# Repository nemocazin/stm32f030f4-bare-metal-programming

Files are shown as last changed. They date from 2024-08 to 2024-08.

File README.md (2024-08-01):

# STM32F030F4 Bare metal programming





## Table of content

 * [General project information](#general-project-information)
 * [Electronic board design](#electronic-board-design)
 * [Embedded programming and test design](#embedded-programming-and-test-design)
 * [Contact](#contact)

## General project information

This product was developed as part of a fourth-year project in the Embedded Systems program at Polytech Lille with an another student. It consisted in designing an electronic board to measure temperature and store the values in an EPROM-type memory. We had to create the board and the programming ourselves, __in a context of mass production__. As a result, we had to work as if we were in a company, meaning we had to carry out all the design stages of a product. 

__This project is focused on the test and maintenance part of the project__. Whether we were testing the physical board or the programming part, we had to do our best to ensure that the board worked in spite of the environment and all its constraints.

The project is therefore divided in __two parts__ : the physical part with the electronic board, and the programming part with the embedded program and the tests carried out on it.

## Electronic board design

This part consists of designing the electronic board. The purpose of this board is to __measure temperature and store measured values in an EPROM-type memory__. We were then asked to design certain components, such as the temperature sensor. 

We then designed the board on Kicad-6 and drew up the schematic and routing. In the end, the board was designed on Polytech Lille's site, from manufacturing to soldering.

We also carried out tests on the board to see how it performed in certain types of environment. 

The board design files can be found in the _"PCB"_ folder of the current directory.

## Embedded programming and test design

The programming of the card was mainly __carried out in the C programming language and using bare metal programming__.

We also used the _"check.h"_ library to carry out unit tests and ensure the proper functioning of our code.

Nucleo boards were available to transfer our file to our microcontroller

## Contact

Created by [@nemocazin] & Antoine Cegarra

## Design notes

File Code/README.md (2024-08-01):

# STM32F030F4 Bare metal programming
# __Embedded Programming Part__

## Table of content

 * [General project information](#general-project-information)
 * [Makefile](#makefile)
 * [tests directory](#tests-directory)
 * [src directory](#src-directory)
 * [lib directory](#lib-directory)
 * [build directory](#build-directory)
 * [Picture](#picture)
 * [Documentation used](#documentation-used)
 * [Contact](#contact)

## General design information

For the embedded programming part of this project, we had to code the ARM Cortex microcontroller using bare metal programming. This program is therefore in the form of an .elf file to be injected into the microcontroller via the ARM JTAG connector. In addition, we had to run unit tests all around the code to check that it worked properly.

## Makefile

The makefile is made up of several targets, each of which performs a specific task.
 - The __main target__ compiles files in the _"src"_ directory using the _"arm-none-eabi-gcc"_ compiler. This needs its linker, which can be found in the _"lib"_ directory. This compiler generates an .elf file which can be injected into the microcontroller via the ARM JTAG connector. As we're creating embedded code, we optimize the size of the .elf file with the __"-O1"__ option. This option is only set to 1, because from 2 onwards, the compiler transforms optimizations made in the microcontroller startup file into functions not present in the libraries on the school's computers, as these libraries are not downloadable at school. These functions are, for example, memcpy and memset, which replace the optimization already carried out for copying SRAM into flash. Additionally, while testing the sensor voltage to temperature conversion function, we noticed that the "arm-none-eabi-gcc" compiler is not capable of using the "float" data type. ". However in our case, it is necessary to use it for the conversion. We then did research to activate floating points but we had to modify the compiler linker and the "mfloat-abi" option did not work even with the hard value.
- the __test target__ is used to create a test executable. These tests are only performed on the _"functions"_ file, as it is the only file with testable functions. We also use the gcc compiler instead of arm-none-eabi-gcc to create the executable file without errors.
- the __load target__ connects to the Nucleo board, enabling the embedded program to be transferred to the microcontroller.
- the __clean target__ deletes temporary files from the _"build"_ directory.
- the __coverage target__ is used to create files displaying the program's coverage. 

## tests directory

This directory __contains the C file for all tests performed__. It performs unit tests on the functions in the _"functions.c"_ file. Tests are mainly performed on register values.

## src directory

This directory contains all the files needed to create the .elf file that can be injected into the microcontroller via the ARM JTAG connector. It is made up of several files: 
 - The __"functions.h"__ file defines all register addresses and function prototypes in its .c file. Register addresses can be found in the datasheet starting on page 38 (Reference manual --> Documentation / Reference Manuals on the 2nd link).
 - the __"functions.c"__ file is used to define all functions and modify all registers to use the components. In general, registers are defined on 16 bits corresponding to 16 pins, and a bit 1 must be set at the corresponding register location. However, the _GPIOA_MODER register_ is defined on 32 bits, so you need to work on 2 bits for each pin. 
 - the __"stm32_startup"__ file is used to configure the microcontroller, since we're programming in bare metal. We then need to define each handler and each corresponding section for it to work. We must also add that the SRAM is 4kb and the Flash is 16kb. This file has been adapted from the tutorial available in the documentation (1st link).
 - the __"main"__ file is the file that calls the functions. The _RCC_AHBENR register_ is configured for clock A, which enables PAx pins to be used.
In the __"functions.h"__ and __"functions.h"__ files, defines vary depending on whether the file is used on an X86 machine or not. This is to enable testing of register values and avoid volatile conflicts. 

## lib directory

This directory contains libraries used when compiling and transferring the .elf file :
 - the __"stm32f030f4.ld"__ file corresponds to the linker used by the compiler thanks to the -T option and it explains how the different sections of the startup file must be brought together to create the .elf file. It also contains zone definitions, addresses and memory sizes.
 - the __"stm32nucleo.cfg"__ file is the file allowing the connection with the Nucleo debug board.

## build directory

This directory corresponds to the directory where the compiled files are stored. These files are erased during the "make clean" command.

## Picture

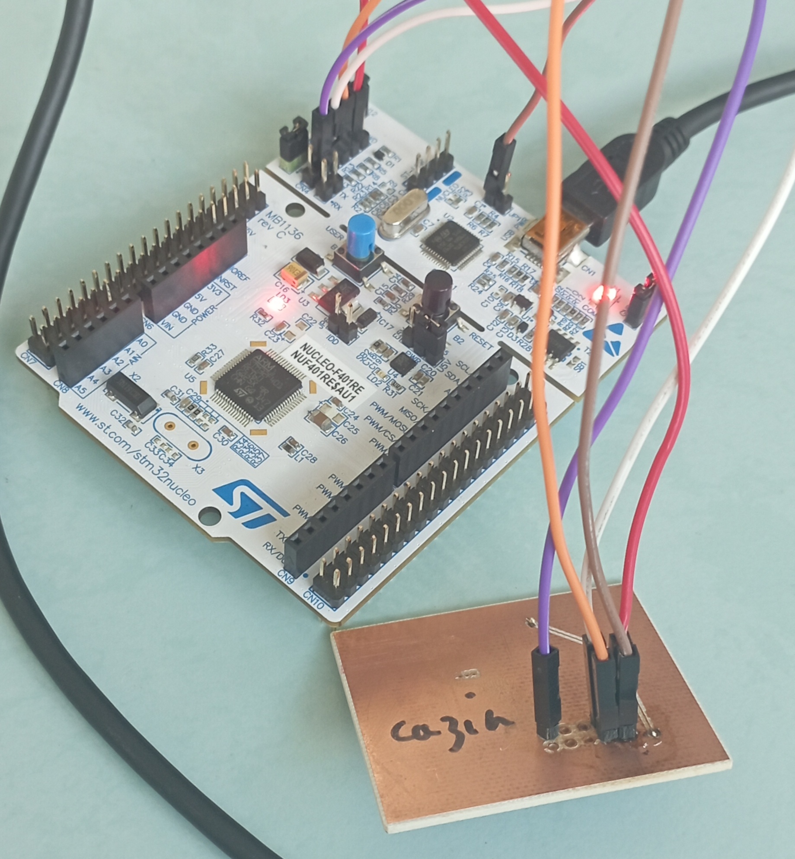
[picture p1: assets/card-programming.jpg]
Card programmation


## Documentation used

* _[Bare Metal - From zero to blink](https://linuxembedded.fr/2021/02/bare-metal-from-zero-to-blink)_
* _[Arm Cortex-M0 Datasheet](https://www.st.com/en/microcontrollers-microprocessors/stm32f030f4.html#documentation)_
* _[Bare metal STM32 Examples](https://github.com/joved-git/Bare_Metal_STM32/blob/master/stm32f103x/stm32_startup_f103x.c)_
* _[Functions of the lib "check.h"](https://libcheck.github.io/check/doc/check_html/check_4.html)_
* _[Options of the arm-none-eabi-gcc compiler](https://gcc.gnu.org/onlinedocs/gcc/ARM-Options.html)_
* _[Forum on floating points for arm-none-eabi-gcc compiler](https://stackoverflow.com/questions/54534700/enabling-floating-point-emulation-in-gcc-arm-none-eabi)_

## Contact

Created by [@nemo.cazin.etu] & Antoine Cegarra

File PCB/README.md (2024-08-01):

# STM32F030F4 Bare metal programming
# __PCB Conception Part__

## Table of content

 * [General project information](#general-project-information)
 * [Schematic design](#cchematic-design)
    * [STM32F030F4 ARM Cortex microcontroller configuration](#stm32f030f4-arm-cortex-microprocessor-configuration)
    * [M24C01 EPROM memory configuration](#m24c01-eprom-memory-configuration)
    * [MCP9700 temperature sensor configuration](#mcp9700-temperature-sensor-configuration)
    * [ARM JTAG connector configuration](#arm-jtag-connector-configuration)
    * [Other components](#other-components)
    * [Decoupling capacitors](#decoupling-capacitors)
    * [TestPoints documentation](#testpoints-documentation)
 * [PCB design](#pcb-design)
 * [Gerber files](#gerber-files)
 * [Soldering](#soldering)
 * [Documentation used](#documentation-used)
 * [Contact](#contact)

## General design information

This project enabled us to design an electronic board for mass production. This put us in a real design situation, so we had to be rigorous in our work and explanations.
For the design of this electronic board, several components were imposed on us. Firstly, the microcontroller is an __STM32F030F4 Arm Cortex__ with a 32-bit RISC-V core. Next, we had to use a __1kbit M24C01 EPROM memory__ on the I2C serial bus. Last but not least, a __Low-Power Linear Active MCP9700 temperature sensor__ was required.
With this information on the components we needed, we began the schematic of our board.

## Schematic design

### STM32F030F4 ARM Cortex microcontroller configuration

As we're using an ARM Cortex microcontroller, we had to do a lot of research to create the schematic around this component. First of all, the __NRST pin__ corresponds to the reset and a 0.1uF capacitor is connected. This information comes from the microcontroller documentation, so we did the same. 
The __BOOTO pin__ is used to control the microcontroller's start-up mode. _When the pin is in the low state (0)_, the microcontroller starts normally from its internal flash memory, where the user program is stored. On the contrary, _when the pin is high (1)_, the microcontroller starts up in special boot mode. This means it will attempt to boot from a different boot source, such as a connected programming device (like an ST-Link or bootloader), or from external memory (like separate flash memory). We've therefore chosen to connect this pin to a 3-pin connector linked to VCC or GND, so as to manually select the microcontroller's start-up mode. This can be seen as manual debugging.
__Pins PF0 and PF1__ correspond to clock management, for which we also used the microcontroller documentation which gave us the schematic. We also used an 8MHz quartz clock, which is the microcontroller frequency.

### M24C01 EPROM memory configuration

To manage the M24C01 EPROM memory component, several pins are connected directly to the microcontroller input/output pins: 
 - __The SDA pin__ is used to transmit data between the EEPROM and the master device. Data to be written to or read from the EEPROM are transmitted via this line. It is linked to pin PA10 of the microcontroller, corresponding to I2C management from master to slave.
 - __The SCL pin__ provides a synchronization clock for serial communication between the EEPROM and the master device. This clock ensures that data is transmitted and received synchronously between the peripherals. It is connected to pin PA9 of the microcontroller.
 - __Pins E0, E1 and E2__ on an EPROM are used to configure the device address. These pins define the EPROM address on the I2C bus. When one of the pins is connected to ground (GND), it sets the least significant bit of the EPROM address to 0. If it is left floating or connected to a high voltage (VCC), it will set this bit to 1. These pins are then connected to pins PA4, PA3, PA2 of the microcontroller.
 - __Pin WC__ controls memory write protection. _When pin WC is held low (0)_ or connected to ground (GND), this indicates that memory write protection is enabled. This means that EEPROM write operations are disabled or protected from modification. On the other hand, _when pin WC is held high (1)_ or connected to a supply voltage (VCC), this indicates that write protection is disabled, allowing normal write operations on the EEPROM memory. This pin is also connected to pin PA7 of the microcontroller. We've also added a 3-pin connector for manual debugging.
This component also operates at 5V, so it is connected directly to VCC for power supply.
Pull-up resistors have been added to initialize the SDA, SCL and EPROM pins to the high state when the electronic board is powered up. This prevents random data from being written to memory. 

### MCP9700 temperature sensor configuration

The MCP9700 temperature sensor is easy to use. __A single output pin named TEMP__ gives the temperature value at several voltage levels. We connected it to the PA1 input/output pin of the microcontroller. This component also operates at 5V, so it's connected directly to VCC for power supply.

### ARM JTAG connector configuration

This connector allows you to control the power supply to the electronic board, as well as program the microntrolleur and perform simple debugging. This component operates at 5V, so it's connected directly to VCC for power supply.
We use two pins for this component: 
 - __The SWDIO pin__ is used to transmit data between the debugger and the microcontroller. This is a bidirectional data line where debug instructions, programming data and read data can be transmitted in both directions. We then connected it to the PA13 input/output pin of the microcontroller.
 - __The SWDCLK pin__ is used to synchronize communication between the debugger and the microcontroller. This clock ensures that data is transmitted synchronously and consistently between the two devices. We then connected it to the PA14 input/output pin on the microcontroller.

### Other components

We've added __two debugging LEDs__ on pins PA0 and PA5 of the microcontroller.

### Decoupling capacitors

The imposed components need decoupling capacities in order to function correctly: 
 - the STM32F030F4 microcontroler needs __5 decoupling capacitors__: C4 at 1uF, C5 at 10nF, C6 at 100nF, C8 at 4.7uF and C10 at 100nF.
 - the M24C01 serial EEPROM memory requires __one decoupling capacitor__ C9 at 100nF.
 - the MCP9700 temperature sensor requires __one decoupling capacitor__ of C7 at 1uF.

### TestPoints documentation

We've added testpoints to check the voltages of certain critical tracks, and also to potentially add additional components. These testpoints also serve as a means of debugging: 
 - __TP1__ is connected to the PB1 input/output pin to potentially add a component
 - __TP2__ is connected to the microcontroller's VCC pin to monitor the voltage value and modify it if necessary
 - __TP3__ is connected to input/output pin PA6 to potentially add a component
 - __TP4__ is connected to the temperature sensor's temperature output pin to monitor output voltage values
 - __TP5__ is connected to the EPROM pin of the EPROM to check voltage and also control EPROM protection manually
 - __TP6__ is connected to the SWCLK pin of the JTAG connector to check synchronization clock voltages 
 - __TP7__ is connected to the SWCLK pin of the JTAG connector if data is being transmitted

## PCB design

For the creation of the PCB, we wanted to do mostly single-sided to facilitate production. In the end, we had to make a track on the underside.
For component footprints other than those specified, we used those from the SparkFun library. 
To place the components, we assembled them together as shown in the schematic. We also grouped the testpoints together to facilitate debugging. Component decoupling capabilities have also been glued to the respective components.
Long tracks for VCC and GND run around the board, which is not optimized but will work in our application.
The result is a 47x40 mm board, with a ground plane on each side.

## Gerber files

We left the Gerber files in the directory in a ZIP file. These are used to create the stencils for the electronic board. These files can be used on a Gerber Viewer like site : [Gerber Viewer](https://www.pcbway.com/project/OnlineGerberViewer.html); 

## Soldering

We soldered the components to the board using tin. As the components are very small, soldering them was a bit tricky.
Here's the soldered board :

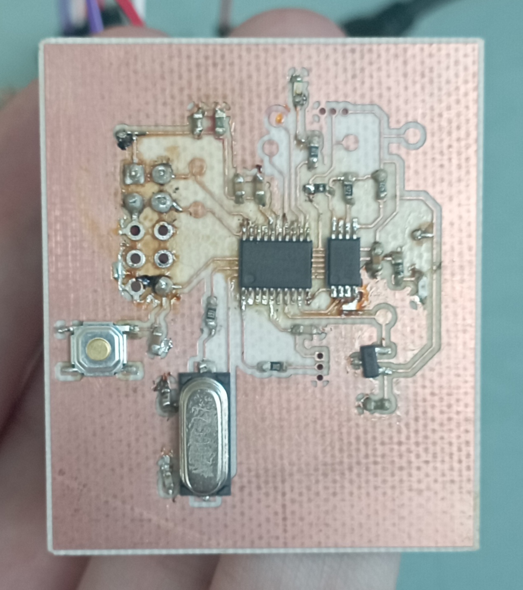
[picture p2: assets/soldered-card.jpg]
Soldered card


## Documentation used

* _[STM32F030F4 microcontroler](https://www.st.com/en/microcontrollers-microprocessors/stm32f030f4.html)_
* _[STM32F030F4 microcontroller hardware consideration](https://www.google.com/url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)_
* _[M24C01 serial EEPROM memory](https://www.st.com/en/memories/m24c01-r.html)_
* _[MCP9700 temperature sensor](https://www.microchip.com/en-us/product/mcp9700)_
* _[MCP9700 temperature sensor hardware consideration](http://ww1.microchip.com/downloads/en/devicedoc/20001942g.pdf)_

## Contact

Created by [@nemocazin] & Antoine Cegarra

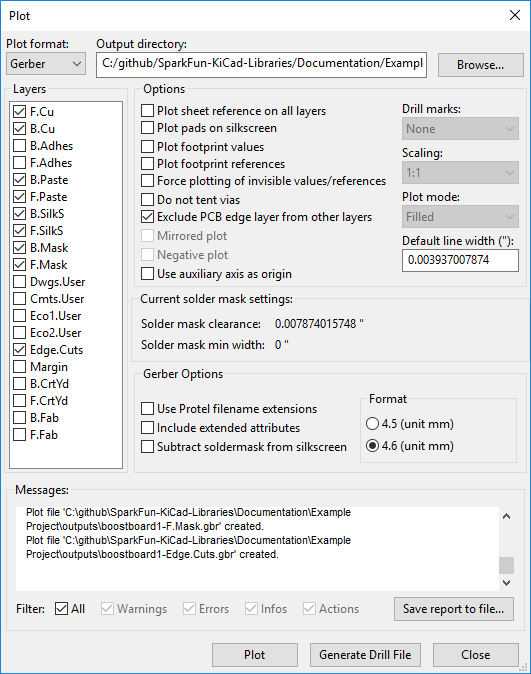
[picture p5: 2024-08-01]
PCB/SparkFun-KiCad-Libraries-master/Documentation/Pictures/PlotSettings.png

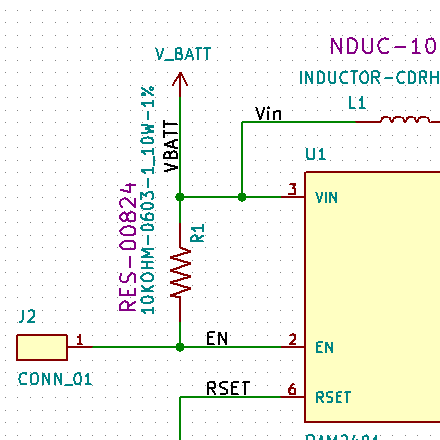
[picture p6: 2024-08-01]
PCB/SparkFun-KiCad-Libraries-master/Documentation/Pictures/eeschema.png

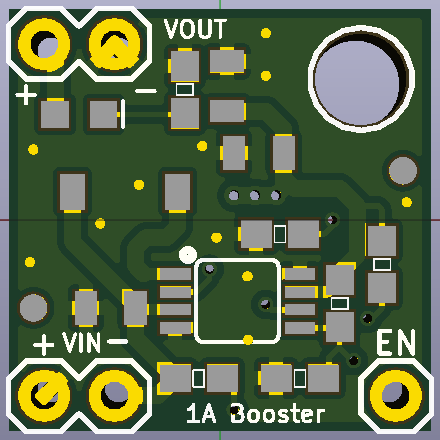
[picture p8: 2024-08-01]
PCB/SparkFun-KiCad-Libraries-master/Documentation/Pictures/ExampleGreen3DView.png

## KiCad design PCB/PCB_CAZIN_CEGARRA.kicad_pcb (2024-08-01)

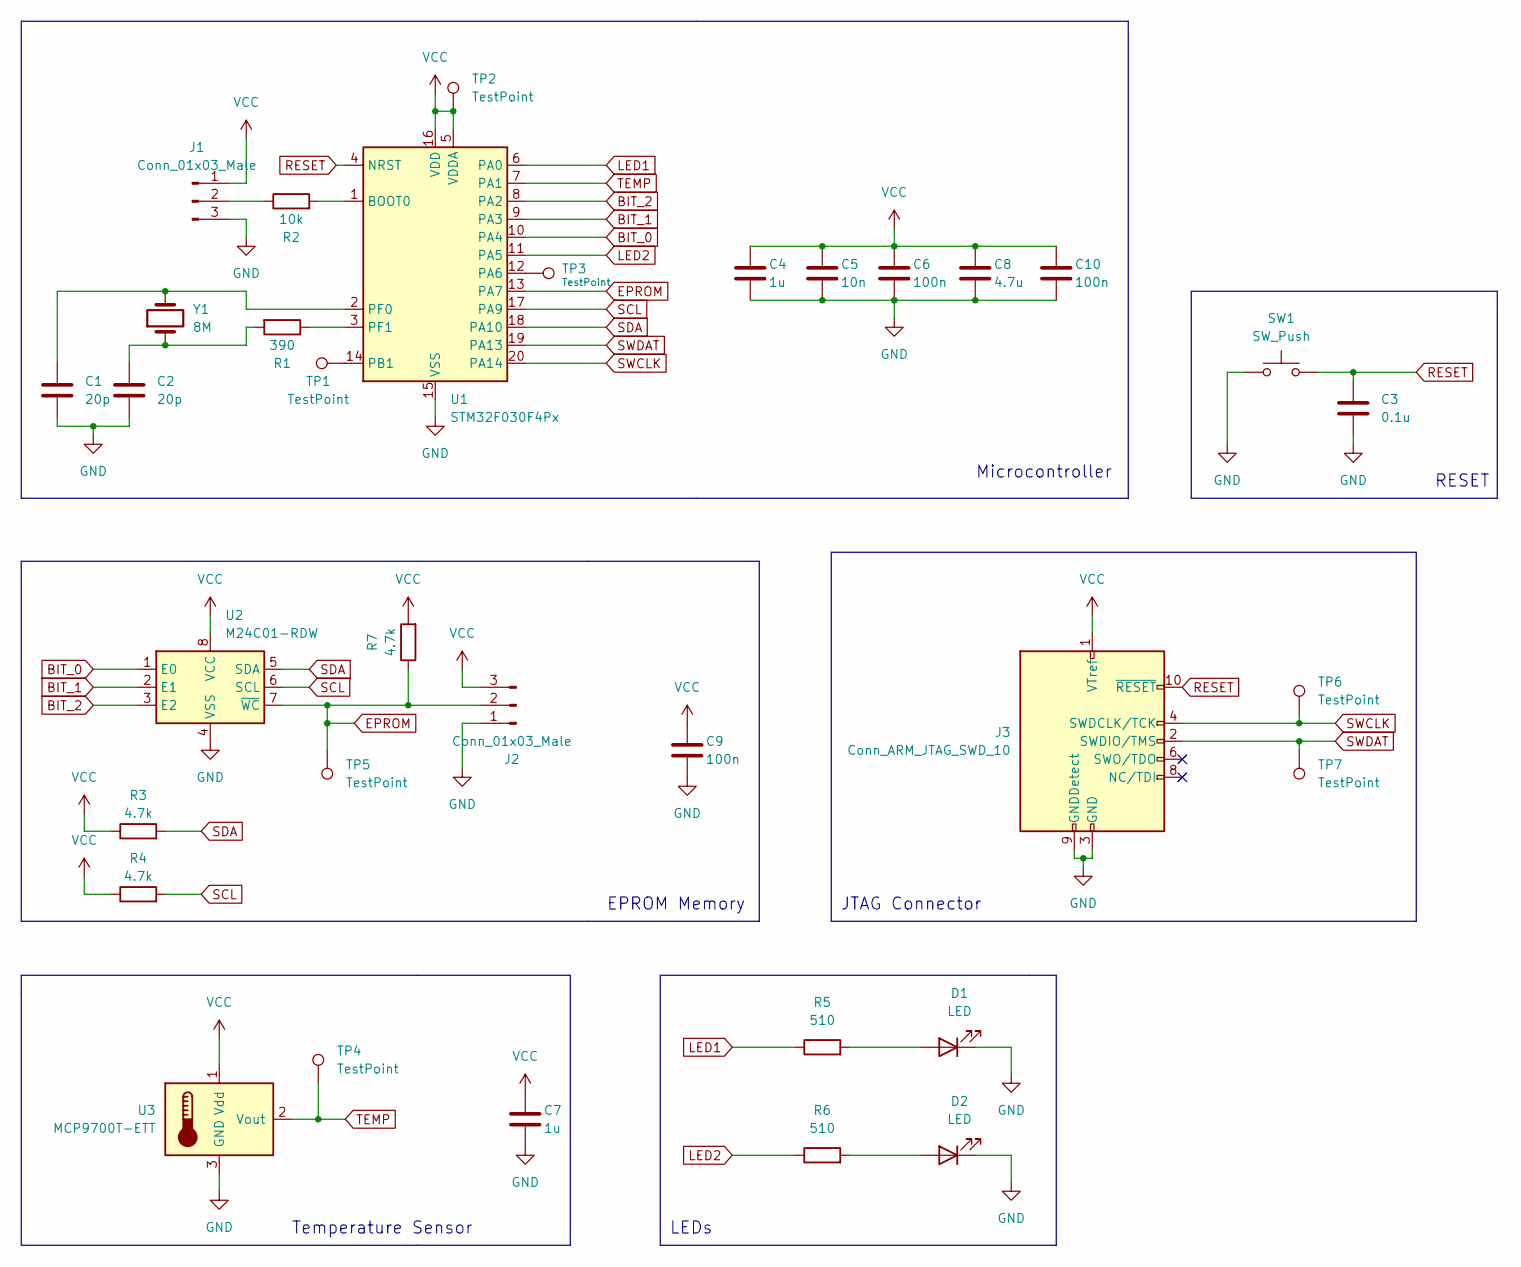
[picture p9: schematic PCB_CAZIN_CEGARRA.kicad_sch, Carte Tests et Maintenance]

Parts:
C1, C2: 20p; C_0603_1608Metric_Pad1.08x0.95mm_HandSolder
C3: 0.1u; C_0603_1608Metric_Pad1.08x0.95mm_HandSolder
C4, C7: 1u; C_0603_1608Metric_Pad1.08x0.95mm_HandSolder
C5: 10n; C_0603_1608Metric_Pad1.08x0.95mm_HandSolder
C6, C9, C10: 100n; C_0603_1608Metric_Pad1.08x0.95mm_HandSolder
C8: 4.7u; C_0603_1608Metric_Pad1.08x0.95mm_HandSolder
D1, D2: LED; LED_0603_1608Metric_Pad1.05x0.95mm_HandSolder
J1, J2: Conn_01x03_Male; PinHeader_1x03_P1.00mm_Vertical
J3: Conn_ARM_JTAG_SWD_10; PinHeader_2x05_P2.54mm_Vertical
R1: 390; R_0603_1608Metric_Pad0.98x0.95mm_HandSolder
R2: 10k; R_0603_1608Metric_Pad0.98x0.95mm_HandSolder
R3, R4, R7: 4.7k; R_0603_1608Metric_Pad0.98x0.95mm_HandSolder
R5, R6: 510; R_0603_1608Metric_Pad0.98x0.95mm_HandSolder
SW1: SW_Push; TACTILE_SWITCH_SMD_5.2MM
TP1, TP2, TP3, TP4, TP5, TP6, TP7: TestPoint; TestPoint_Pad_D1.5mm
U1: STM32F030F4Px; TSSOP-20_4.4x6.5mm_P0.65mm
U2: M24C01-RDW; TSSOP-8_4.4x3mm_P0.65mm
U3: MCP9700T-ETT; SOT-23
Y1: 8M; Crystal_SMD_HC49-SD

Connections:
BIT_0: U1.10 (PA4), U2.1 (E0)
BIT_1: U1.9 (PA3), U2.2 (E1)
BIT_2: U1.8 (PA2), U2.3 (E2)
EPROM: J2.2, R7.1, TP5.1, U1.13 (PA7), U2.7 (~WC)
GND: C1.2, C2.2, C3.2, C4.2, C5.2, C6.2, C7.2, C8.2, C9.2, C10.2, D1.1 (K), D2.1 (K), J1.3, J2.1, J3.3 (GND), J3.5 (GND), J3.9 (GNDDetect), SW1.1, U1.15 (VSS), U2.4 (VSS), U3.3 (GND)
LED1: R5.1, U1.6 (PA0)
LED2: R6.1, U1.11 (PA5)
unnamed: C1.1, U1.2 (PF0), Y1.2
unnamed: C2.1, R1.2, Y1.1
unnamed: D1.2 (A), R5.2
unnamed: D2.2 (A), R6.2
unnamed: J1.2, R2.1
unnamed: R1.1, U1.3 (PF1)
unnamed: R2.2, U1.1 (BOOT0)
unnamed: TP1.1, U1.14 (PB1)
unnamed: TP3.1, U1.12 (PA6)
RESET: C3.1, J3.10 (~RESET), SW1.2, U1.4 (NRST)
SCL: R4.2, U1.17 (PA9), U2.6 (SCL)
SDA: R3.2, U1.18 (PA10), U2.5 (SDA)
SWCLK: J3.4 (SWDCLK/TCK), TP6.1, U1.20 (PA14)
SWDAT: J3.2 (SWDIO/TMS), TP7.1, U1.19 (PA13)
TEMP: TP4.1, U1.7 (PA1), U3.2 (Vout)
VCC: C4.1, C5.1, C6.1, C7.1, C8.1, C9.1, C10.1, J1.1, J2.3, J3.1 (VTref), R3.1, R4.1, R7.2, TP2.1, U1.5 (VDDA), U1.16 (VDD), U2.8 (VCC), U3.1 (Vdd)

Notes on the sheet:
RESET
Microcontroller
EPROM Memory
Temperature Sensor
JTAG Connector
LEDs

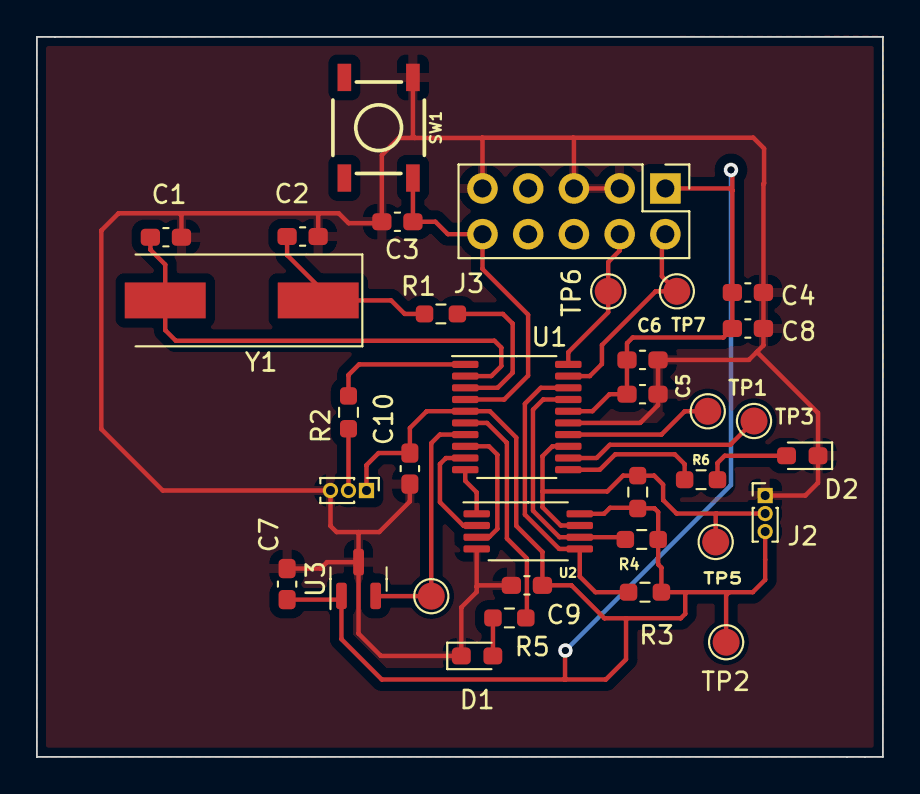
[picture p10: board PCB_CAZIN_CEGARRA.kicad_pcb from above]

Board: 2 copper layers, 47.0 x 40.0 mm, 34 parts (0 on the bottom side), 23 nets.

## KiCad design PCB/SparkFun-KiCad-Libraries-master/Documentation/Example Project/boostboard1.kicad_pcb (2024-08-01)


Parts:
C1, C2, C3: 22UF-0805-6.3V-20%; 0805
D1: LED-RED0603; LED-0603
FD1, FD2: FIDUCIAL1X2; FIDUCIAL-1X2
H1: STAND-OFF
J1, J3: CONN_02; 1X02
J2: CONN_01; 1X01
JP1: JUMPER-SMT_2_NO; SMT-JUMPER_2_NO_SILK
L1: INDUCTOR-CDRH-4.7UH; INDUCTOR_2.2UH
LOGO1: SFE_LOGO_NAME_FLAME.1_INCH; SFE_LOGO_NAME_FLAME_.1
LOGO2: OSHW-LOGOS; OSHW-LOGO-S
R1: 10KOHM-0603-1_10W-1%; 0603
R2, R4: 100KOHM-0603-1_10W-1%; 0603
R3, R5: 820KOHM-0603-1_10W-1%; 0603
R6: 4.7KOHM-0603-1_10W-1%; 0603
U1: PAM2401; MSOP8

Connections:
/EN: J2.1, R1.2, U1.2 (EN)
/FB: JP1.2, R3.1, R4.2, U1.5 (FB)
/GND: C1.2, C2.2, C3.2, J1.1, J3.1, R2.2, R4.1, R6.1, U1.4 (AGND), U1.8 (PGND)
/LX: L1.P$2 (2), U1.1 (LX)
/RSET: R2.1, U1.6 (RSET)
/VBATT: C1.1, J1.2, L1.P$1 (1), R1.1, U1.3 (VIN)
/VCC: C2.1, C3.1, D1.A, J3.2, R3.2, R5.2, U1.7 (OUT)
unnamed: D1.C, R6.2
unnamed: JP1.1, R5.1

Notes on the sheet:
1A Booster
Jumper: Open for 5.0V operation Closed for 3.3V operation
Input
Output
Input Range: 0.9 to 4.75V For full output capacity, upwards of 3A may be required. For max operation, calculate with P=IV, using 6 watts. At 3.7V, Iin = 1.62A



Board: 2 copper layers, 15.2 x 15.2 mm, 21 parts (3 on the bottom side), 9 nets.

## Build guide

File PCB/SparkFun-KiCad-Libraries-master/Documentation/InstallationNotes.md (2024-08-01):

Installation Notes
----------------

* [The KiCad site](http://kicad.org/)

**KiCad installation**

* Uninstall previous versions of KiCad
* Download KiCad stable version 4.0.5 from [http://kicad.org/download/](http://kicad.org/download/windows/) and install
* After install, you'll be prompted to install "Wings 3D", check this box to be redirected to [http://www.wings3d.com/](http://www.wings3d.com/)
* Download and install the stable release 2.1.5

**Using the libraries**

* Create a local project (this is necessary because projects hold library path information)
* Open the "Schematic Library Editor"
* Prefrences -> Component Libraries
  * Remove all libraries from list
  * Add -> navigate to SparkFun-KiCad-Libraries -> select all .lib files -> open, then hit OK
  * Test by selecting an active library.  All sparkfun libraries should be displayed.  Close the library editor
* Open the "PCB Footprint Editor"
* Preferences -> Footprint Library Manager
  * Remove all (if any) libraries, hit OK
* Preferences -> Footprint Libraries Wizard
  * Next (files on my computer)
  * Navigate to SparkFun-KiCad-Libraries -> select all .mod files and hit ok
  * Next
  * Select for this project only
  * Next
  * Close the editor
* Save the project (Green arrow into extern HDD icon, no menu exists)

Now, this project is linked to the libraries.  Open a schematic and place components.  See KiCad enginursday post for converting from schematic into board (Note: You need to have nets for this to work... not just unconnected components)

**License Information**

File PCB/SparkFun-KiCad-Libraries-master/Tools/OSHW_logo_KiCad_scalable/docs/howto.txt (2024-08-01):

How to make your own:
---------------------

Watch / read this first:

* http://www.kicad.org/display/KICAD/Videos+by+zupnikal
  * PCB layout with KiCad => https://www.youtube.com/playlist?list=PL67B2290F4C62B5F2
    * KiCad #1 - Mounting hole clearance and cut-out zone in the copper pour
    * KiCad #2 - Solder mask clearance
    * KiCad #3 - Using 'FreeRoute' to create a simple board
    * KiCad #4 - Adding the OSHW logo to your layout
    * KiCad #5 - Using custom logos in your design

The last two videos should be helpful for how to create a custom .emp file from images.

* http://www.re-innovation.co.uk/web12/index.php/en/blog-75/230-adding-logo-to-kicad

If you use linux (which you should), you don't have to use the online-scaler. Just use the scripts!

---

* Create a folder to hold your new footprint library.
* Copy the scripts 'make_lib.sh' and 'scale.pl' into that folder.
* Make sure these files are executable (chmod u+x ...).
* Copy your custom .emp file into that foler.

* Run the 'make_lib.sh' script as follows:

./make_lib.sh input-file.emp lib-name.mod START END

START and END are placeholders for positive integer numbers (1,2,3...) that determine
the range of created footprint sizes. The units are metric (mm).

The 'lib-name.mod' file will show up in the 'lib' sub-folder. Add it to your pcbnew
library settings as usual.

Footprints that are created for back-layers are automagically mirrored horizontally.
To place them onto a back-layer, hover the mouse-pointer over them and press 'f' for 'flip'.

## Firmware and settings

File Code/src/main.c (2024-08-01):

/**
 * @brief      This file contains the main function with calls to component management functions
 *
 * @author     Némo CAZIN & Antoine CEGARRA
 * @date       2024
 */

#include <stdio.h>
#include <stdlib.h>
#include <string.h>
#include "functions.h"

int main(){
    while(1){
        RCC_AHBENR |= GPIOAEN;
        LED1_blink();
        LED2_blink();
    }
    return 0;
}

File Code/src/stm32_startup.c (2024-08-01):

#include <stdio.h>
#include <stdint.h>
/*#include <stdlib.h>
#include <string.h>*/

#define SRAM_START 0x20000000U
#define SRAM_SIZE  (4U * 1024U)            /* 16 kb  */
#define SRAM_END   ((SRAM_START) + (SRAM_SIZE))

#define STACK_START SRAM_END

extern uint32_t _etext;
extern uint32_t _sdata;
extern uint32_t _edata;
extern uint32_t _la_data;

extern uint32_t _sbss;
extern uint32_t _ebss;

extern int main();

void Reset_Handler(void);
void NMI(void)                  __attribute__ ((weak, alias("Default_Handler")));
void HardFault(void)            __attribute__ ((weak, alias("Default_Handler")));
void SVCall(void)               __attribute__ ((weak, alias("Default_Handler")));
void PendSV(void)               __attribute__ ((weak, alias("Default_Handler")));
void SysTick(void)              __attribute__ ((weak, alias("Default_Handler")));
void WWDG(void)                 __attribute__ ((weak, alias("Default_Handler")));
void RTC(void)                  __attribute__ ((weak, alias("Default_Handler")));
void FLASH(void)                __attribute__ ((weak, alias("Default_Handler")));
void RCC(void)                  __attribute__ ((weak, alias("Default_Handler")));
void EXTI0_1(void)              __attribute__ ((weak, alias("Default_Handler")));
void EXTI2_3(void)              __attribute__ ((weak, alias("Default_Handler")));
void EXTI4_15(void)             __attribute__ ((weak, alias("Default_Handler")));
void DMA_CH1(void)              __attribute__ ((weak, alias("Default_Handler")));
void DMA_CH2_3(void)            __attribute__ ((weak, alias("Default_Handler")));
void DMA_CH4_5(void)            __attribute__ ((weak, alias("Default_Handler")));
void ADC(void)                  __attribute__ ((weak, alias("Default_Handler")));
void TIM1_BRK_UP_TRG_COM(void)  __attribute__ ((weak, alias("Default_Handler")));
void TIM1_CC (void)             __attribute__ ((weak, alias("Default_Handler")));
void TIM3(void)                 __attribute__ ((weak, alias("Default_Handler")));
void TIM6(void)                 __attribute__ ((weak, alias("Default_Handler")));
void TIM14(void)                __attribute__ ((weak, alias("Default_Handler")));
void TIM15(void)                __attribute__ ((weak, alias("Default_Handler")));
void TIM16(void)                __attribute__ ((weak, alias("Default_Handler")));
void TIM17(void)                __attribute__ ((weak, alias("Default_Handler")));
void I2C1(void)                 __attribute__ ((weak, alias("Default_Handler")));
void I2C2(void)                 __attribute__ ((weak, alias("Default_Handler")));
void SPI1(void)                 __attribute__ ((weak, alias("Default_Handler")));
void SPI2(void)                 __attribute__ ((weak, alias("Default_Handler")));
void USART1(void)               __attribute__ ((weak, alias("Default_Handler")));
void USART2(void)               __attribute__ ((weak, alias("Default_Handler")));
void USART3_4_5_6(void)         __attribute__ ((weak, alias("Default_Handler")));
void USB(void)                  __attribute__ ((weak, alias("Default_Handler")));



uint32_t vectors[] __attribute__ ((section(".isr_vector"))) ={ 
    STACK_START,
    (uint32_t) &Reset_Handler,
    (uint32_t) &NMI,
    (uint32_t) &HardFault,
    (uint32_t) &SVCall,
    (uint32_t) &PendSV,
    (uint32_t) &SysTick,
    (uint32_t) &WWDG,
    0,
    (uint32_t) &RTC,
    (uint32_t) &FLASH,
    (uint32_t) &RCC,
    (uint32_t) &EXTI0_1,
    (uint32_t) &EXTI2_3,
    (uint32_t) &EXTI4_15,
    0,
    (uint32_t) &DMA_CH1,
    (uint32_t) &DMA_CH2_3,
    (uint32_t) &DMA_CH4_5,
    (uint32_t) &ADC,
    (uint32_t) &TIM1_BRK_UP_TRG_COM,
    (uint32_t) &TIM1_CC,
    0,
    (uint32_t) &TIM3,
    (uint32_t) &TIM6,
    0,
    (uint32_t) &TIM14,
    (uint32_t) &TIM15,
    (uint32_t) &TIM16,
    (uint32_t) &TIM17,
    (uint32_t) &I2C1,
    (uint32_t) &I2C2,
    (uint32_t) &SPI1,
    (uint32_t) &SPI2,
    (uint32_t) &USART1,
    (uint32_t) &USART2,
    (uint32_t) &USART3_4_5_6,
    0,
    (uint32_t) &USB,
}; 

void Reset_Handler(void) {
	//copy .data section to SRAM
	uint32_t size = (uint32_t)&_edata - (uint32_t)&_sdata;
	
	uint8_t *pDst = (uint8_t*)&_sdata; //sram
	uint8_t *pSrc = (uint8_t*)&_la_data; //flash
	
	for(uint32_t i =0 ; i < size ; i++)
	{
		*pDst++ = *pSrc++;
	}
	
	//Init. the .bss section to zero in SRAM
	size = (uint32_t)&_ebss - (uint32_t)&_sbss;
	pDst = (uint8_t*)&_sbss;
	for(uint32_t i =0 ; i < size ; i++)
	{
		*pDst++ = 0;
	}

	//__libc_init_array();
	
	main();
	
}

void Default_Handler(void) {
    while (1);
}

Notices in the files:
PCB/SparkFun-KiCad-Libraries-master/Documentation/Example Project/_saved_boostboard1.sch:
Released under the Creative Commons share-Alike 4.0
